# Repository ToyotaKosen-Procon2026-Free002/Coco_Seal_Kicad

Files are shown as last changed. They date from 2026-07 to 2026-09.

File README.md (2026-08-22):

# ココ・シール ハードウェア設計

## 表面実装部品

[JLCPCB表面実装可能部品検索](https://jlcpcb.com/parts)

データシートとか型番もここから持ってきたい

## データシートや製品ページ

### 基本的モジュール

- MCU(ESP32-C3-WROOM-02-N4)
  - [データシート](https://documentation.espressif.com/esp32-c3-wroom-02_datasheet_en.pdf)
  - [JLCPCB](https://jlcpcb.com/partdetail/3281215-ESP32_C3_WROOM_02N4/C2934560)
  - [購入ページ](https://akizukidenshi.com/catalog/g/g117493/)

- LoRa(E220-900T22S(JP))
  - [データシート](https://dragon-torch.tech/rf-modules/lora/e220-900t22s-jp/)
  - [購入ページ](https://akizukidenshi.com/catalog/g/g131361/)

- 3.3v 600mA レギュレータ(AP2112K-3.3TRG1)
  - [JLCPCB](https://jlcpcb.com/partdetail/TECHPUBLIC-AP2112K_33TRG1/C23380830)
  - [データシート](./datasheets/AP2112K.pdf)

- OLED(SSD1306)
  - [データシート](https://akizukidenshi.com/goodsaffix/ssd1306.pdf)
  - [購入ページ](https://akizukidenshi.com/catalog/g/g112031/)

- ブザー(PKB24SPCH3601-B0)
  - [JLCPCB](https://jlcpcb.com/partdetail/MurataElectronics-PKB24SPCH3601B0/C440255)
  - [データシート](https://akizukidenshi.com/goodsaffix/murata-piezo-buzzer.pdf)

- 2色LED(LT6CU7R)
  - [購入ページ](https://akizukidenshi.com/catalog/g/g108982/)
  - [データシート](https://akizukidenshi.com/goodsaffix/LT6CU7R.pdf)

### バッテリー回路

- 充電IC(TP4056-42-ESOP8)
  - [JLCPCB](https://jlcpcb.com/partdetail/17264-TP4056_42ESOP8/C16581)
  - [データシート](https://www.lcsc.com/datasheet/C16581.pdf)

- Li-ion保護IC(DW01A)
  - [JLCPCB](https://jlcpcb.com/partdetail/PUOLOP-DW01A/C351410)
  - [データシート](https://hmsemi.com/downfile/DW01A.PDF)

- デュアルMOSFET(FS8205A)
  - [JLCPCB](https://jlcpcb.com/partdetail/TECHPUBLIC-FS8205A/C2830320)
  - [データシート](./datasheets/FS8205A.pdf)

### 基本部品

- コンデンサ
  - 0.1μF [JLCPCB](https://jlcpcb.com/partdetail/YAGEO-CC0603KRX7R9BB104/C14663)
  - 1μF [JLCPCB](https://jlcpcb.com/partdetail/16531-CL10A105KB8NNNC/C15849)
  - 10μF [JLCPCB](https://jlcpcb.com/partdetail/14236-CL31A106KBHNNNE/C13585)
  - 470μF [JLCPCB](https://jlcpcb.com/partdetail/HonorElec-RVT1C471M0810/C3341)

- USB-Cコネクタ
  - [JLCPCB](https://jlcpcb.com/partdetail/SHOUHAN-TYPE_C_16PIN_2MD_073/C2765186)

- 抵抗
  - 100 [JLCPCB](https://jlcpcb.com/partdetail/23502-0603WAF1000T5E/C22775)
  - 330 [JLCPCB](https://jlcpcb.com/partdetail/23865-0603WAF3300T5E/C23138)
  - 1k [JLCPCB](https://jlcpcb.com/partdetail/21904-0603WAF1001T5E/C21190)
  - 10k [JLCPCB](https://jlcpcb.com/partdetail/26547-0603WAF1002T5E/C25804)
  - 4.7k [JCLPCB](https://jlcpcb.com/partdetail/23889-0603WAF4701T5E/C23162)
  - 5.1k [JLCPCB](https://jlcpcb.com/partdetail/23913-0603WAF5101T5E/C23186)
  - 100k [JLCPCB](https://jlcpcb.com/partdetail/26546-0603WAF1003T5E/C25803)

- タクトスイッチ
  - SOS [購入ページ](https://akizukidenshi.com/catalog/g/g109827/)
  - Common [JLCPCB](https://jlcpcb.com/partdetail/SHOUHAN-TS665TPZJ/C557600)
  - Reset [JLCPCB](https://jlcpcb.com/partdetail/Korean_HropartsElec-K2_6639DP_B4SW04/C83205)

### その他

- ESD保護素子(D+D-の静電気などの保護)(TPD2EUSB30A)
  - [JLCPCB](https://jlcpcb.com/partdetail/TexasInstruments-TPD2EUSB30ADRTR/C94934)
  - [データシート](https://www.ti.com/cn/lit/ds/symlink/tpd2eusb30a.pdf)

- MMOSFET(AO3400A)
  - [JLCPCB](https://jlcpcb.com/partdetail/Alpha_OmegaSemicon-AO3400A/C20917)
  - [データシート](./datasheets/AO3400A.pdf)

## GPIO割り当て

Strapping pins に割り当てられているため、2, 8, 9 はちょっと使いづらい

|GPIO|機能|入出力|周辺回路|プルアップ/プルダウン|備考|
|:-:|:-:|:-:|:-:|:-:|:-:|
|0|ADC|IN|バッテリー電圧分圧回路|-|R1=R2=100kΩくらい|
|1|GPIO|IN|タクトスイッチ1|プルアップ|
|2|GPIO|OUT|2色LED_R|プルアップ|Strapping Pin, 起動時に誤点灯の可能性あり|
|3|GPIO|OUT|ブザー制御MOSFET|-|MOSFETを通してバッテリーから直で電源供給予定|
|4|I2C|I/O|OLED SCK|-|おそらくモジュール側でPU実装済|
|5|I2C|I/O|OLED SDA|-|おそらくモジュール側でPU実装済|
|6|GPIO|OUT|LoRa M1|-|
|7|GPIO|OUT|LoRa M0|-|
|8|GPIO|OUT|2色LED_G|プルアップ|Strapping Pin, 起動時に誤点灯の可能性あり|
|9|GPIO|IN|タクトスイッチ2|プルアップ|Strapping Pin, 押しながら起動するとDownload Mode として起動|
|10|GPIO|IN|LoRa AUX|-|
|18|USB D-|I/O|USB-C D-|-|ESD保護素子を挟む|
|19|USB D+|I/O|USB-C D+|-|ESD保護素子を挟む|
|20|UART TXD|OUT|LoRa RXD|-|固定|
|21|UART RXD|IN|LoRa TXD|-|固定|

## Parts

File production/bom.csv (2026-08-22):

Designator | Footprint | Quantity | Value | LCSC Part #
BT1 | JST_PH_S2B-PH-K_1x02_P2.00mm_Horizontal | 1 | Battery_Cell
BZ1 | BUZ-TH_BD24.3-P15.00_PKB24SPCH3601-B0 | 1 | Buzzer | C440255
C1 | C0603 | 1 | 1μF | C15849
C10, C3 | CAP-SMD_BD8.0-L8.3-W8.3-FD | 2 | 470μF | C3341
C2, C4, C6, C8 | C1206 | 4 | 10μF | C13585
C5, C7, C9 | C0603 | 3 | 0.1μF | C14663
D1, D2 | LED_D5.0mm-3 | 2 | LED_Dual_KAK
J1 | PinSocket_1x07_P2.54mm_Vertical | 1 | E220-900T22S(JP)
Q1 | SOT-23-6 | 1 | FS8205A | C2830320
Q3 | SOT-23-3 | 1 | Q_NMOS_GSD | C20917
R1, R2, R7 | R0603 | 3 | 10K | C25804
R10 | R0603 | 1 | 4.7K | C23162
R11, R12, R16 | R0603 | 3 | 100K | C25803
R13, R15 | R0603 | 2 | 100 | C22775
R14, R8, R9 | R0603 | 3 | 1K | C21190
R3, R4 | R0603 | 2 | 330 | C23138
R5, R6 | R0603 | 2 | 5.1K | C23186
SW1 | SW_PUSH-12mm | 1 | SOS_Button
SW2 | SW-TH_TS665TPZJ | 1 | Common_Button | C557600
SW3 | SW_PUSH_6mm | 1 | Reset_Button | C97440
U1 | Texas_DRT-3 | 1 | TPD2EUSB30A | C94934
U2 | ESP32-C3-WROOM-02 | 1 | ESP32-C3-WROOM-02 | C2934560
U3 | SOIC-8-1EP_3.9x4.9mm_P1.27mm_EP2.41x3.3mm_ThermalVias | 1 | TP4056-42-ESOP8 | C16581
U5 | SOT-23-5 | 1 | AP2112K-3.3 | C23380830
U6 | SOT-23-6 | 1 | DW01A | C351410
U7 | PinSocket_1x04_P2.54mm_Vertical | 1 | SSD1306_OLED
USB1 | USB-C-SMD_TYPE-C-16PIN-2MD-073 | 1 | TYPE-C 16PIN 2MD | C2765186

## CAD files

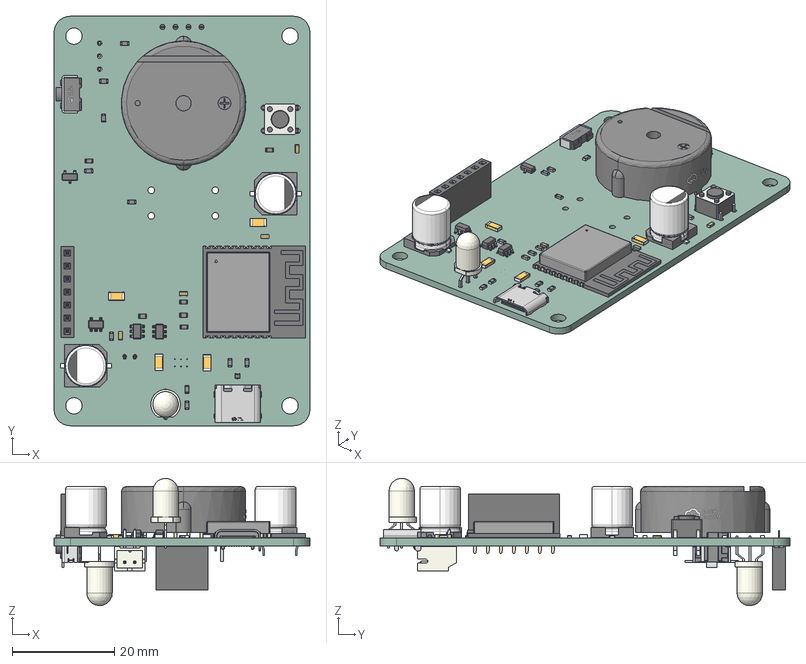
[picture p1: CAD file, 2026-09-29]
CocoSealDevice.step
50.0 x 80.0 x 24.9 mm
C1206_L3.2-W1.6-H1.3 x 4
SOT-23-5
CAP-SMD_BD8.0-L8.3-W8.3-FD x 2
R0603 x 16
C0603_L1.6-W0.8-H0.8 x 4
LED_D5.0mm-3 x 2
SOT-23-3
BUZ-TH_BD24.3-P15.00_PKB24SPCH3601-B0
SW_PUSH_6mm
DRT_3
PinSocket_1x07_P2.54mm_Vertical
SW-TH_TS665TPZJ
SOT-23-6 x 2
ESP32-C3-WROOM-02
USB-C-SMD_TYPE-C-6PIN-2MD-073
JST_S2B_PH_K
PinSocket_1x04_P2.54mm_Vertical
Coco_Seal_hardware_PCB

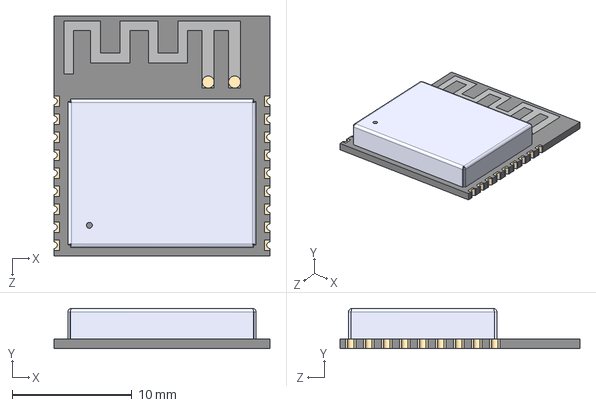
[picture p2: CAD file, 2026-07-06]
simbols/ESP32-C3-WROOM-02-N4.step
18.0 x 3.35 x 20.0 mm

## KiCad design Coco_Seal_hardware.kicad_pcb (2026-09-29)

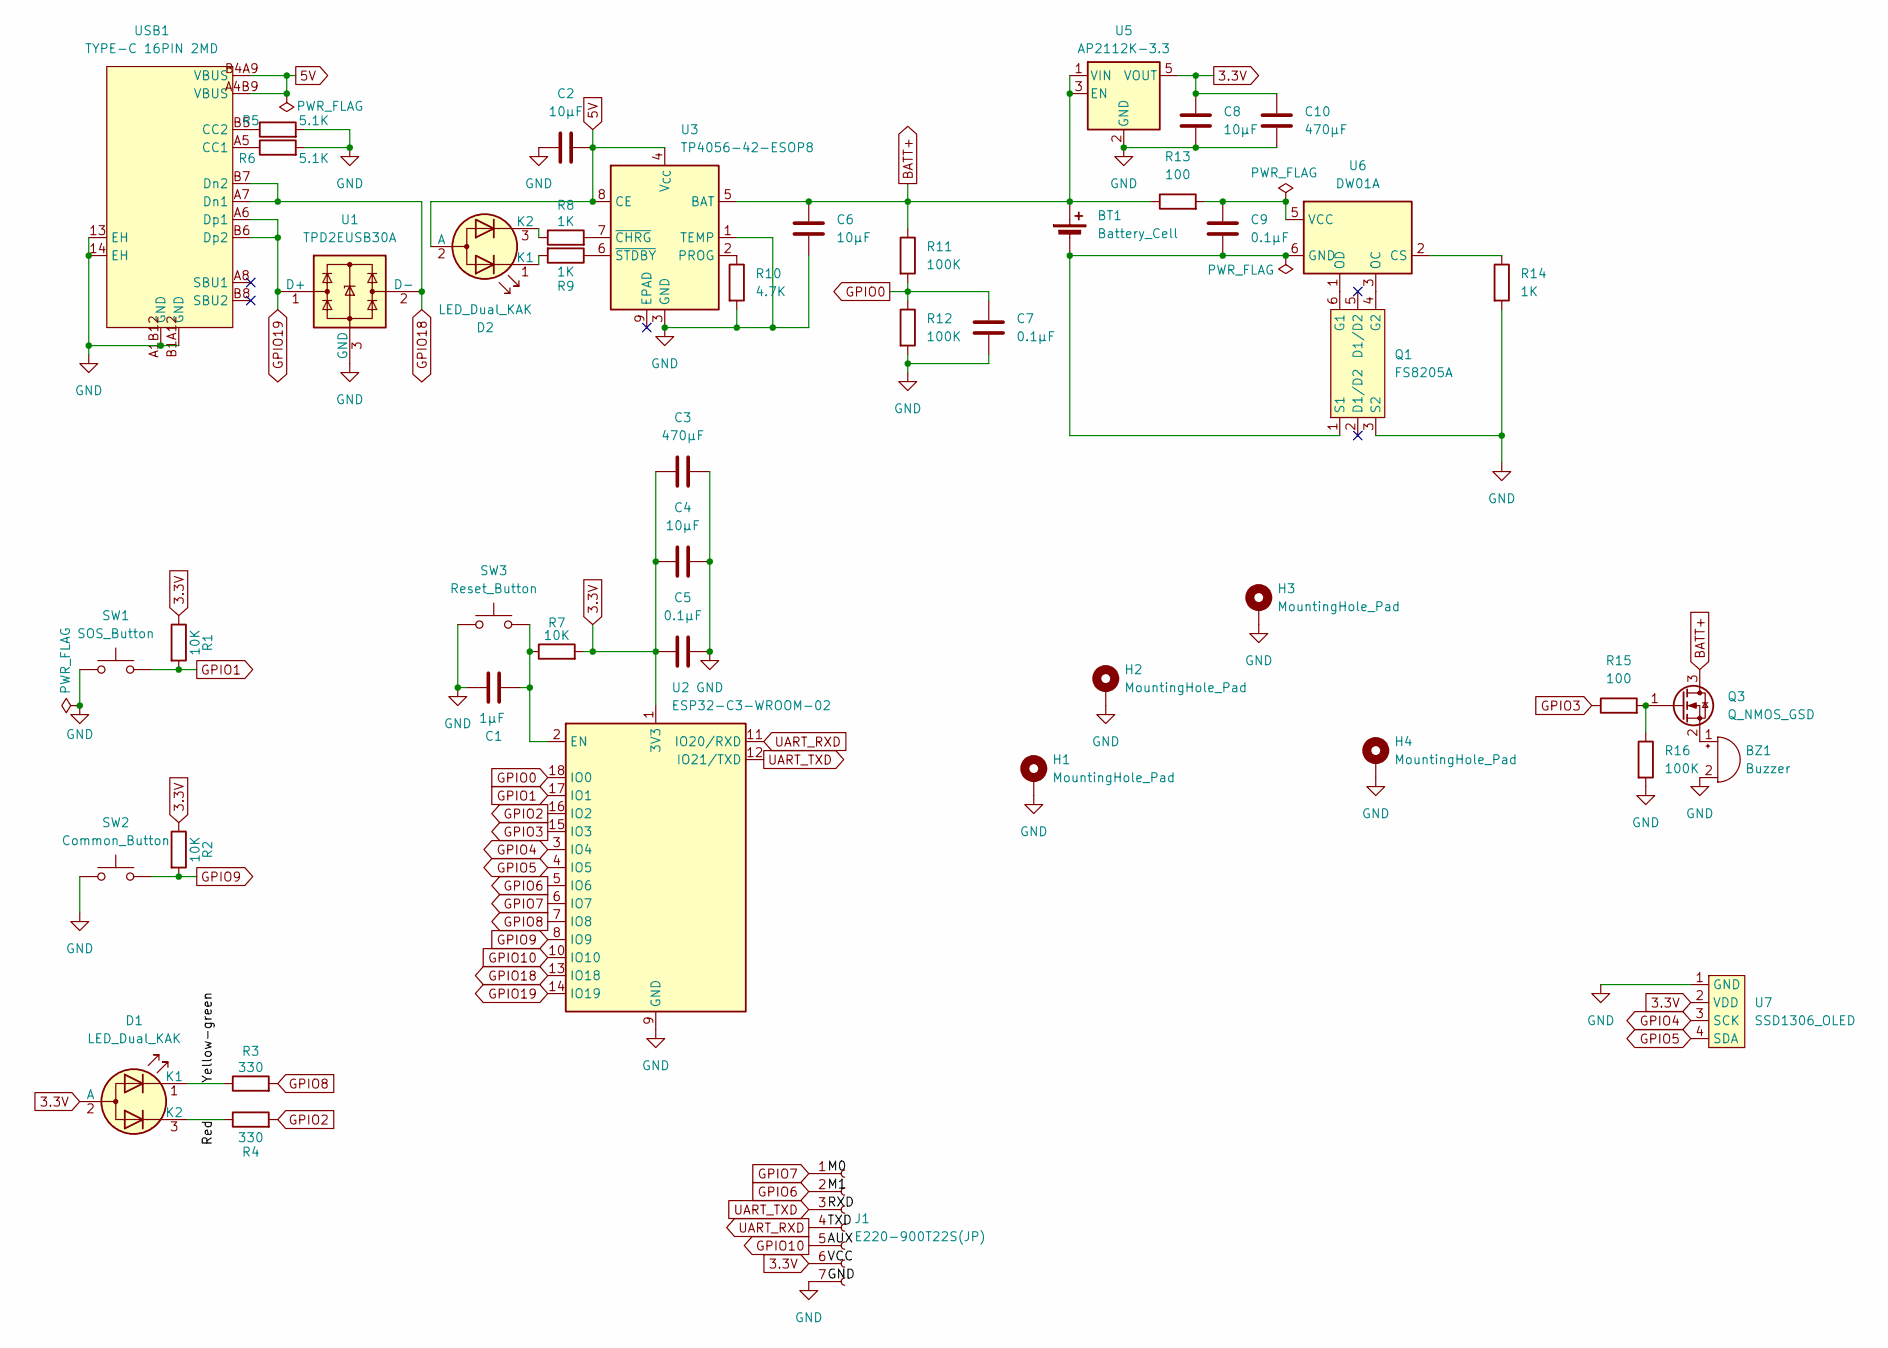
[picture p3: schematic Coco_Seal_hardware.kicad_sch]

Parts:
BT1: Battery_Cell; JST_PH_S2B-PH-K_1x02_P2.00mm_Horizontal
BZ1: Buzzer; BUZ-TH_BD24.3-P15.00_PKB24SPCH3601-B0
C1: 1μF; C0603; LCSC Part C15849
C2, C4, C6, C8: 10μF; C1206; LCSC Part C13585
C3, C10: 470μF; CAP-SMD_BD8.0-L8.3-W8.3-FD; LCSC Part C3341
C5, C7, C9: 0.1μF; C0603; LCSC Part C14663
D1, D2: LED_Dual_KAK; LED_D5.0mm-3
H1, H2, H3, H4: MountingHole_Pad; MountingHole_3.2mm_M3_ISO7380_Pad_TopBottom
J1: E220-900T22S(JP); PinSocket_1x07_P2.54mm_Vertical
Q1: FS8205A; SOT-23-6; LCSC Part C2830320
Q3: Q_NMOS_GSD; SOT-23-3; LCSC Part C20917
R1, R2, R7: 10K; R0603; LCSC Part C25804
R3, R4: 330; R0603; LCSC Part C23138
R5, R6: 5.1K; R0603; LCSC Part C23186
R8, R9, R14: 1K; R0603; LCSC Part C21190
R10: 4.7K; R0603; LCSC Part C23162
R11, R12, R16: 100K; R0603; LCSC Part C25803
R13, R15: 100; R0603; LCSC Part C22775
SW1: SOS_Button; SW_PUSH-12mm
SW2: Common_Button; SW-TH_TS665TPZJ; LCSC Part C557600
SW3: Reset_Button; SW_PUSH_6mm; LCSC Part C97440
U1: TPD2EUSB30A; Texas_DRT-3; LCSC Part C94934
U2: ESP32-C3-WROOM-02; LCSC Part C2934560
U3: TP4056-42-ESOP8; SOIC-8-1EP_3.9x4.9mm_P1.27mm_EP2.41x3.3mm_ThermalVias; LCSC Part C16581
U5: AP2112K-3.3; SOT-23-5; LCSC Part C23380830
U6: DW01A; SOT-23-6; LCSC Part C351410
U7: SSD1306_OLED; PinSocket_1x04_P2.54mm_Vertical
USB1: TYPE-C 16PIN 2MD; USB-C-SMD_TYPE-C-16PIN-2MD-073; MPN TYPE-C 16PIN 2MD(073); LCSC Part C2765186

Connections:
3.3V: C3.1, C4.1, C5.1, C8.1, C10.1, D1.2 (A), J1.6, R1.1, R2.1, R7.2, U2.1 (3V3), U5.5 (VOUT), U7.2 (VDD)
5V: C2.1, D2.2 (A), U3.4 (V_{CC}), U3.8 (CE), USB1.A4B9 (VBUS), USB1.B4A9 (VBUS)
/Red: D1.3 (K2), R4.1
/Yellow-green: D1.1 (K1), R3.1
BATT+: BT1.1 (+), C6.1, Q3.3 (D), R11.1, R13.1, U3.5 (BAT), U5.1 (VIN), U5.3 (EN)
GND: BZ1.2 (-), C1.2, C2.2, C3.2, C4.2, C5.2, C6.2, C7.2, C8.2, C10.2, H1.1 (1_1), H2.1 (1_1), H3.1 (1_1), H4.1 (1_1), J1.7, Q1.3 (S2), R5.2, R6.2, R10.2, R12.2, R14.2, R16.2, SW1.1, SW2.1, SW3.1, U1.3 (GND), U2.9 (GND), U2.19 (GND), U3.1 (TEMP), U3.3 (GND), U5.2 (GND), U7.1 (GND), USB1.13 (EH), USB1.14 (EH), USB1.A1B12 (GND), USB1.B1A12 (GND)
GPIO0: C7.1, R11.2, R12.1, U2.18 (IO0)
GPIO1: R1.2, SW1.2, U2.17 (IO1)
GPIO2: R4.2, U2.16 (IO2)
GPIO3: R15.1, U2.15 (IO3)
GPIO4: U2.3 (IO4), U7.3 (SCK)
GPIO5: U2.4 (IO5), U7.4 (SDA)
GPIO6: J1.2, U2.5 (IO6)
GPIO7: J1.1, U2.6 (IO7)
GPIO8: R3.2, U2.7 (IO8)
GPIO9: R2.2, SW2.2, U2.8 (IO9)
GPIO10: J1.5, U2.10 (IO10)
GPIO18: U1.2 (D-), U2.13 (IO18), USB1.A7 (Dn1), USB1.B7 (Dn2)
GPIO19: U1.1 (D+), U2.14 (IO19), USB1.A6 (Dp1), USB1.B6 (Dp2)
unnamed: BT1.2 (-), C9.2, Q1.1 (S1), U6.6 (GND)
unnamed: BZ1.1 (+), Q3.2 (S)
unnamed: D2.1 (K1), R9.2
unnamed: D2.3 (K2), R8.1
unnamed: Q1.6 (G1), U6.1 (OD)
unnamed: Q1.4 (G2), U6.3 (OC)
unnamed: Q3.1 (G), R15.2, R16.1
unnamed: C1.1, R7.1, SW3.2, U2.2 (EN)
unnamed: R10.1, U3.2 (PROG)
unnamed: R8.2, U3.7 (~CHRG)
unnamed: R9.1, U3.6 (~STDBY)
unnamed: R14.1, U6.2 (CS)
unnamed: C9.1, R13.2, U6.5 (VCC)
unnamed: R6.1, USB1.A5 (CC1)
unnamed: R5.1, USB1.B5 (CC2)
UART_RXD: J1.4, U2.11 (IO20/RXD)
UART_TXD: J1.3, U2.12 (IO21/TXD)

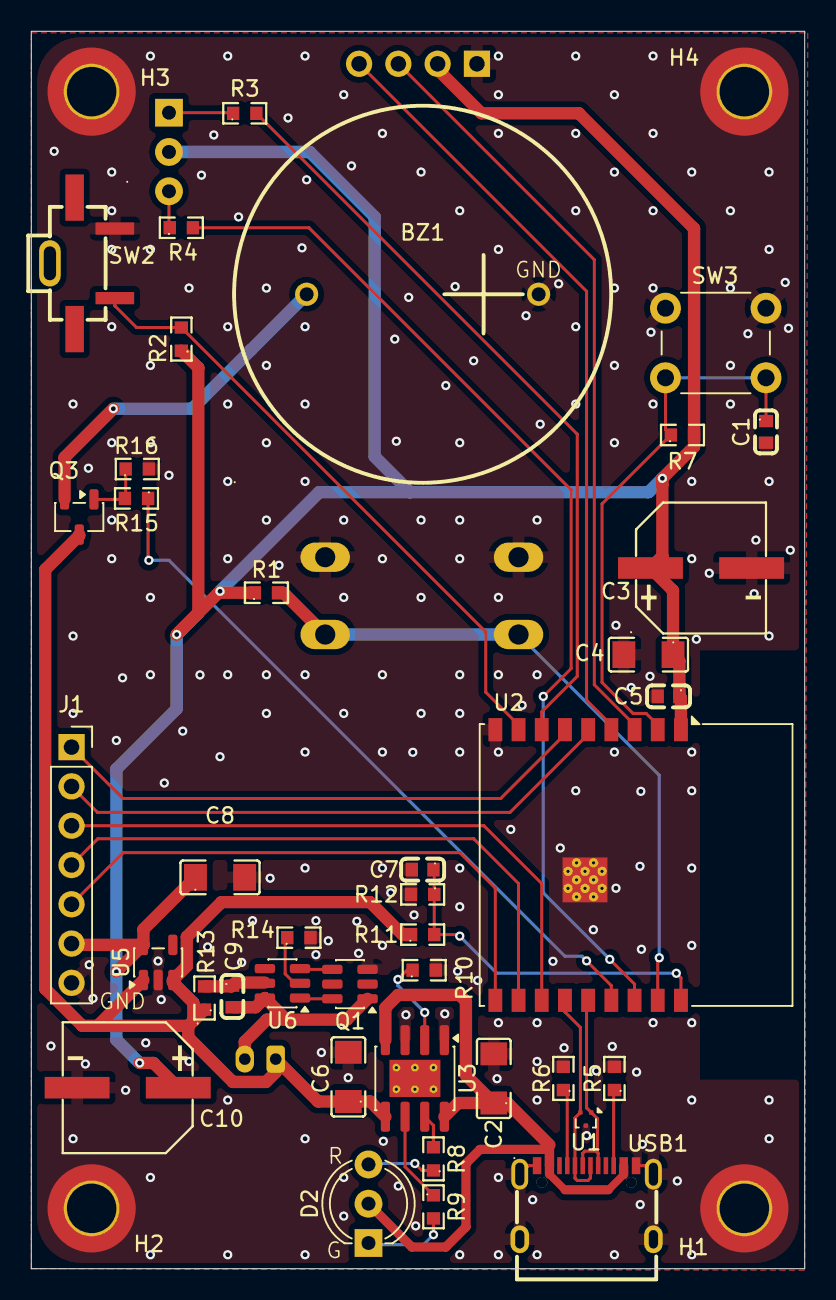
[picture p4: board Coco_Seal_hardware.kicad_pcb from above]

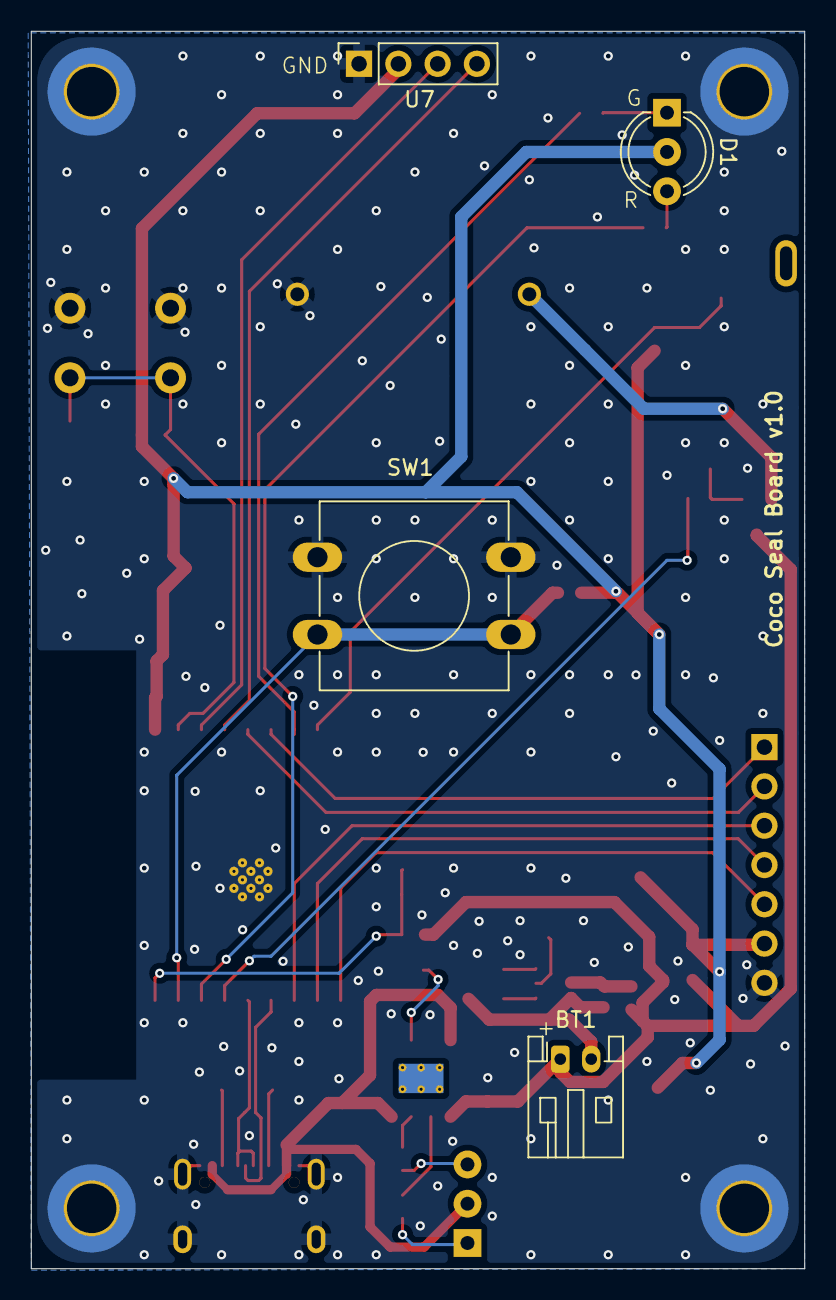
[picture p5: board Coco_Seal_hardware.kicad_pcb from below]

Board: 2 copper layers, 50.0 x 80.0 mm, 47 parts (4 on the bottom side), 36 nets.

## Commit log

2026-07-02 Initial commit~
    [kicad_test.kicad_pcb, kicad_test.kicad_sch]
2026-07-04 基本部品の配置
    [Coco_Seal_hardware.kicad_sch]
2026-07-06 ESP32のシンボルを追加
    [ESP32-C3-WROOM-02-N4.step]
2026-07-08 作成したloraシンボルを追加
    [Coco_Seal_hardware.kicad_sch]
2026-07-08 使用するシンボル設置完了
    [Coco_Seal_hardware.kicad_sch]
2026-07-08 loraとESP32-C3-wroom-02-N4を配線した
    [Coco_Seal_hardware.kicad_sch]
2026-07-08 buzzerとESP32-C3-wroom-02-N4を配線した
    [Coco_Seal_hardware.kicad_sch]
2026-07-08 oledとESP32-C3-wroom-02-N4を配線した
    [Coco_Seal_hardware.kicad_sch]
2026-07-08 swichとESP32-C3-wroom-02-N4を配線した
    [Coco_Seal_hardware.kicad_sch]
2026-07-08 buzeerのマイナスにESP32-C3-wroom-02-N4を配線し直した
    [Coco_Seal_hardware.kicad_sch]
2026-07-08 各パーツのGNDを配線した
    [Coco_Seal_hardware.kicad_sch]
2026-07-08 vccを配線した
    [Coco_Seal_hardware.kicad_sch]
2026-07-09 gitignore編集
2026-07-09 README追加
2026-07-09 README編集
2026-07-09 READMEにGPIO一覧を追加
2026-07-09 GPIO一覧を追加
2026-07-12 README更新, 回路図更新
    [Coco_Seal_hardware.kicad_sch]
2026-07-12 保護回路
    [Coco_Seal_hardware.kicad_sch]
2026-07-12 電源回路
    [Coco_Seal_hardware.kicad_sch]
2026-07-12 回路図いったん完成かな？
    [Coco_Seal_hardware.kicad_sch]
2026-07-23 コンデンサ追加
    [Coco_Seal_hardware.kicad_sch]
2026-08-15 フットプリント調整、基板設計開始、途中かけ
    [Coco_Seal_hardware.kicad_pcb, Coco_Seal_hardware.kicad_sch]
2026-08-19 基板設計中3.3v配線途中
    [Coco_Seal_hardware.kicad_pcb, Coco_Seal_hardware.kicad_sch]
2026-08-21 配線いったん完了
    [Coco_Seal_hardware.kicad_pcb, Coco_Seal_hardware.kicad_sch]
2026-08-21 JLCPCB用にデータを追加
    [Coco_Seal_hardware.kicad_pcb, Coco_Seal_hardware.kicad_sch, bom.csv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]
2026-08-22 基板設計いったん完了
    [Coco_Seal_hardware.kicad_pcb, Coco_Seal_hardware.kicad_sch, bom.csv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]
2026-08-26 ちょっと開いただけ
2026-09-29 3Dモデル出力#
    [CocoSealDevice.step, Coco_Seal_hardware.kicad_pcb, Coco_Seal_hardware.kicad_sch]
